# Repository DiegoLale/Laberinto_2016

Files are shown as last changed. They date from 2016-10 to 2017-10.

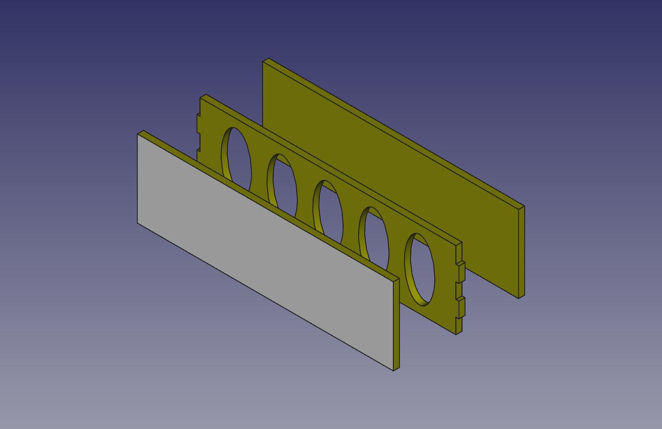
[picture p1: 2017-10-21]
piezas_laberinto/montaje paredes.jpeg

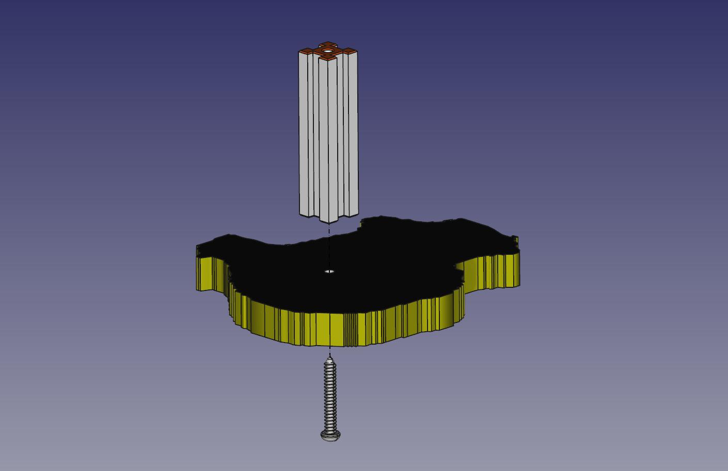
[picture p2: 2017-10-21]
piezas_laberinto/montaje_pivote.jpeg

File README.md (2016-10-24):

# Laberinto_2016
Simple robot para competición de laberinto de la OSHWDem

Toda la información en www.lalebots.com

***14 octubre 2016***

  Creación del repositorio
  
  Añadido primer chasis
  
***16 octubre 2016***

  Modificado chasis
  
    chasisSuperior_v2
    cahsisInferior_v2
    
  Añadidas nuevas piezas
  
    bolaLoca
    TapaBateria
    LlantaLego
    
*** 24 octubre 2016***

  Compartida electrónica

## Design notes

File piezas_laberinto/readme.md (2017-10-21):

Piezas para fabricación de laberinto con paredes de 12mm y distancia de 180mm entre "postes".
Hay una versión imprimible de las paredes y otra que se puede cortar en una cortadora láser.
El espesor de las paredes ha de ser de 12mm por lo que se usa madera de 4mm.
Cada pared está compuesta de tres piezas. una central con huecos que tiene pestañas laterales para encastrar en los "pilares",
Y otras dos planas para las partes exteriores.
El archivo "7paredes.dxf" está optimizado para hacer 7 paredes completas en una cortadora de al menos 52cm x 37mm.
Todos los diseños han sido creados con herramientas libres.
Freecad para los diseños 3d y librecad para los dxf.
Los pivotes están pensados para ser atornillados por debajo a un tablero de 10mm con tornillos din7981 de 25mm o m3 de al menos 20mm

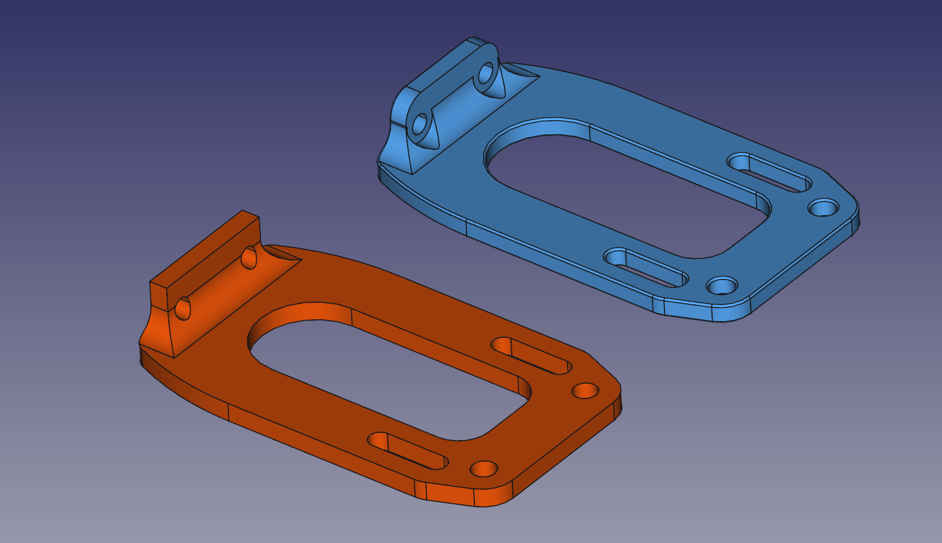
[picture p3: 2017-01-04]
soportes.png

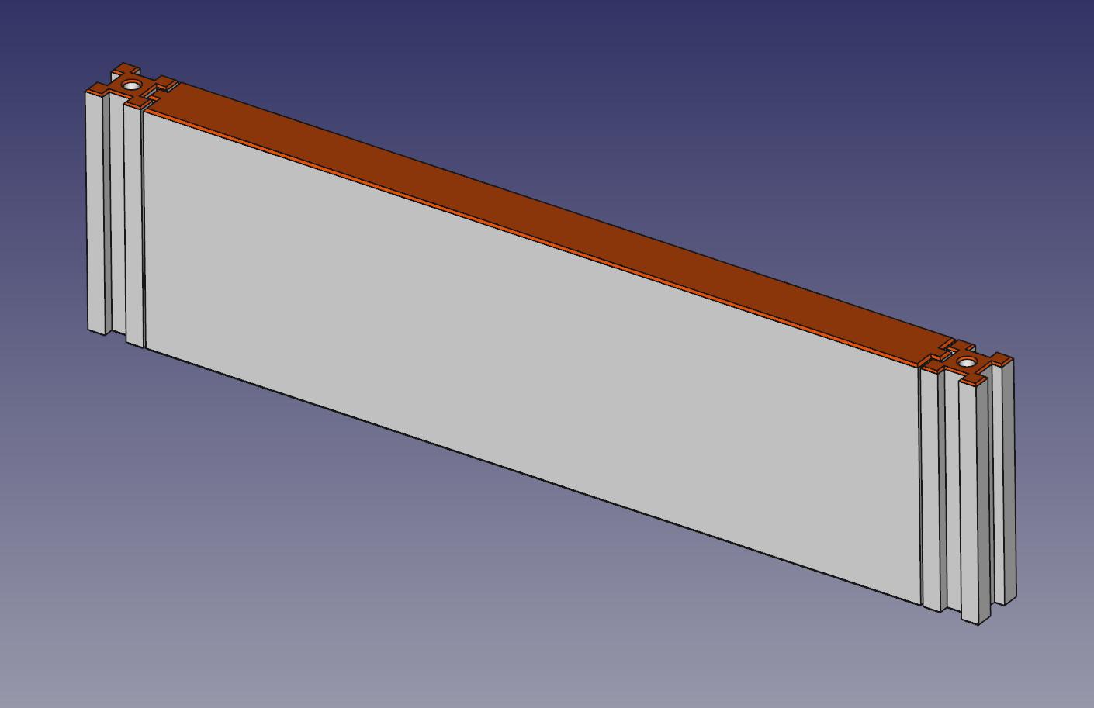
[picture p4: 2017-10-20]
piezas_laberinto/piezas_laberinto.jpeg

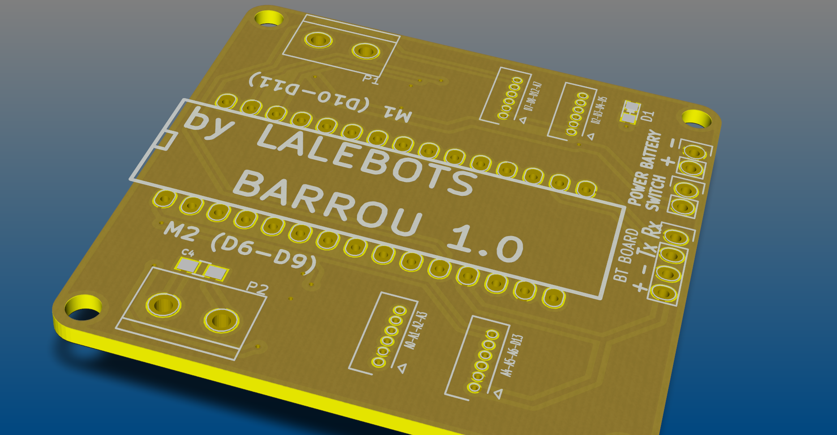
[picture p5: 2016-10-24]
PCB/aneja_2016.png

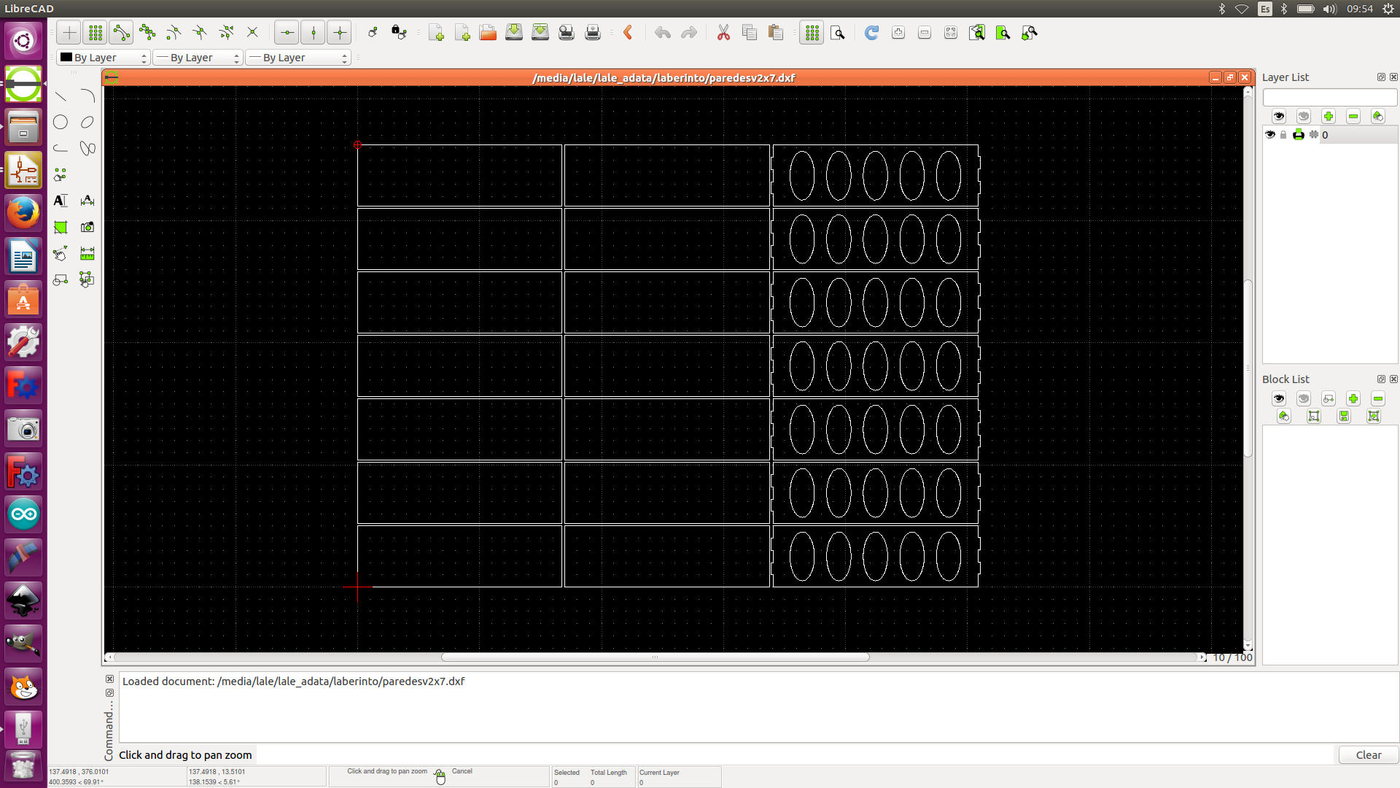
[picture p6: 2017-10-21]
piezas_laberinto/librecad paredes.png

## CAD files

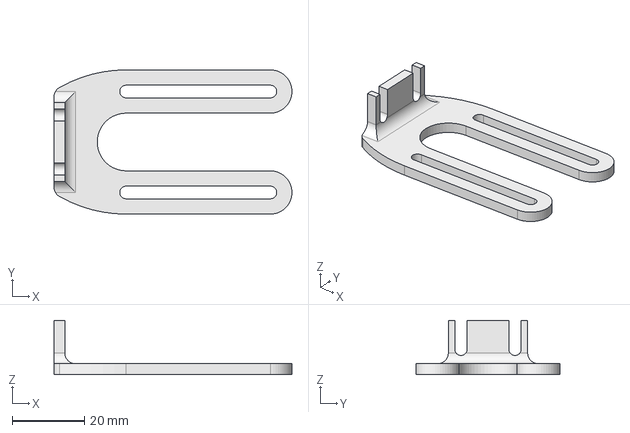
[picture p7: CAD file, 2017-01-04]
freecad/siguelineasSoporte.fcstd
66.0 x 40.0 x 15.0 mm

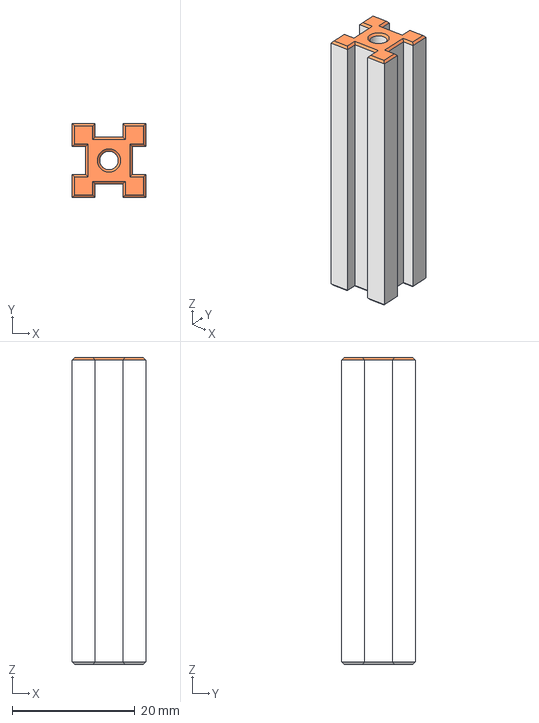
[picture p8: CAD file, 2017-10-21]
piezas_laberinto/pivote.step
12.0 x 12.0 x 50.0 mm

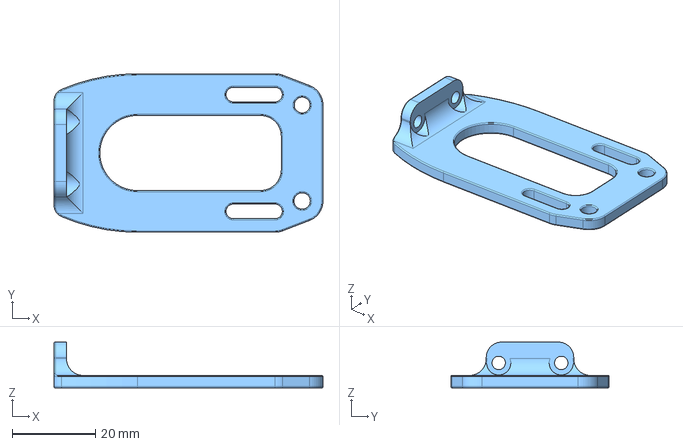
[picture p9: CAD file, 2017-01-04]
step/siguelineasSoportev2.step
64.5 x 38.0 x 11.0 mm

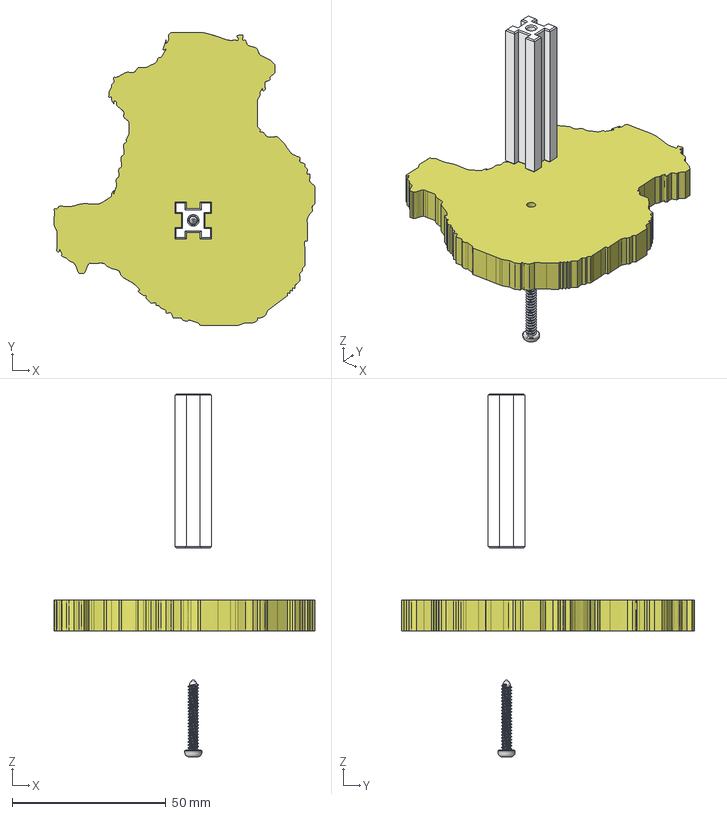
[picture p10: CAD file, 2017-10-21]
piezas_laberinto/montaje pivote.fcstd
84.8 x 95.3 x 118.0 mm
pivote

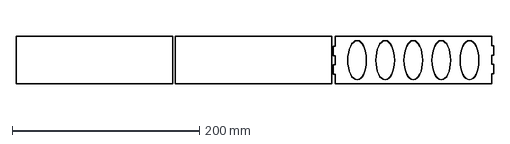
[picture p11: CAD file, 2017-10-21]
piezas_laberinto/#pared para laser.dxf
510.6 x 50.5 mm

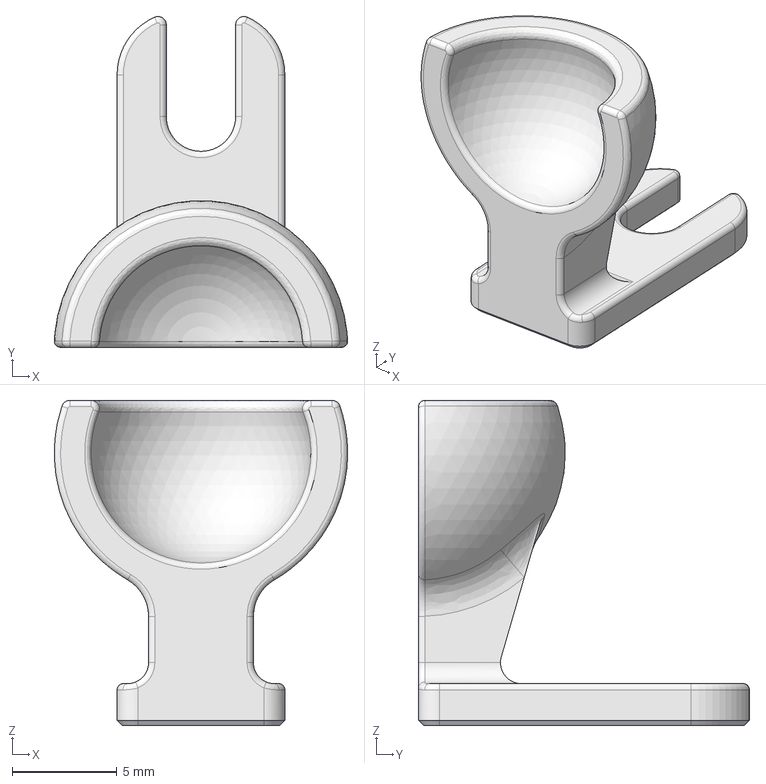
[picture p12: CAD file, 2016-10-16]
step/bolaLoca.step
14.0 x 15.8 x 15.5 mm

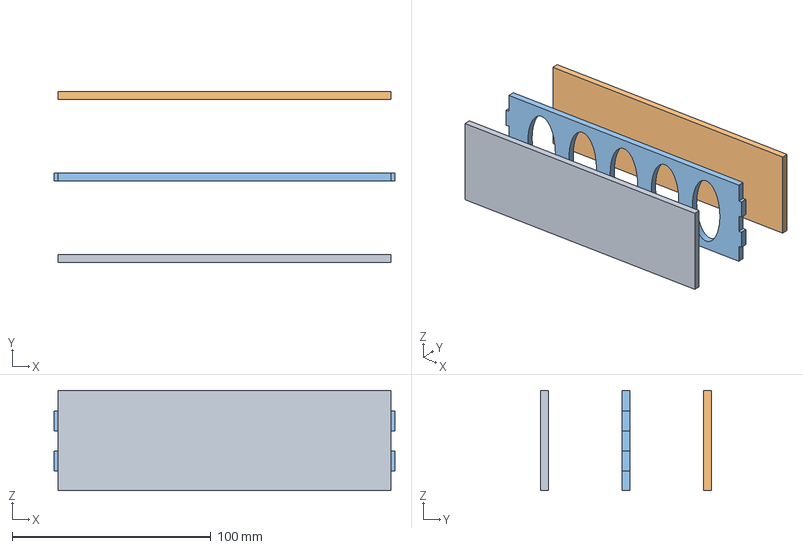
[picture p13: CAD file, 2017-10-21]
piezas_laberinto/montaje paredes.fcstd
171.6 x 86.0 x 50.5 mm
Cubo
Cubo001

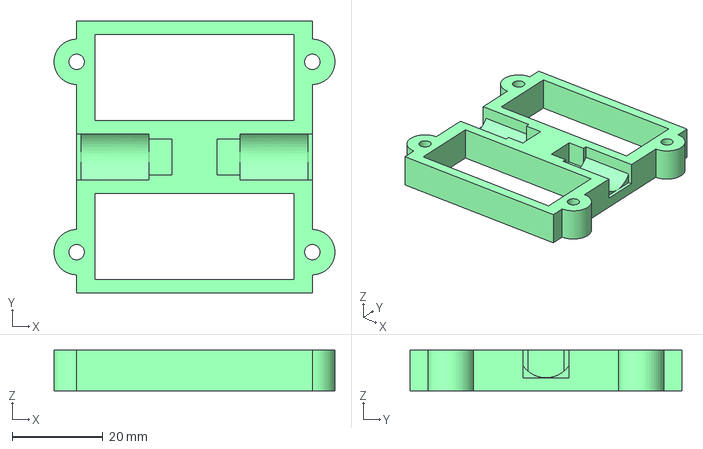
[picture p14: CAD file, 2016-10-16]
step/chasisInferior_v2.step
62.0 x 60.0 x 9.00 mm

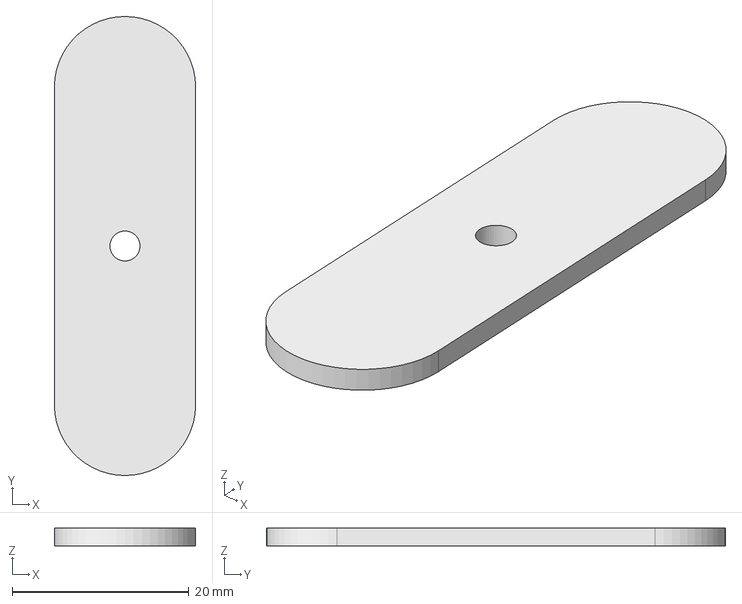
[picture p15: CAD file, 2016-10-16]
step/tapaBateriasSimple.step
16.0 x 52.0 x 2.00 mm

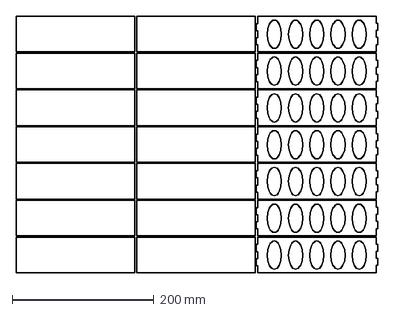
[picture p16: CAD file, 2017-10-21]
piezas_laberinto/7paredes.dxf
510.6 x 362.5 mm

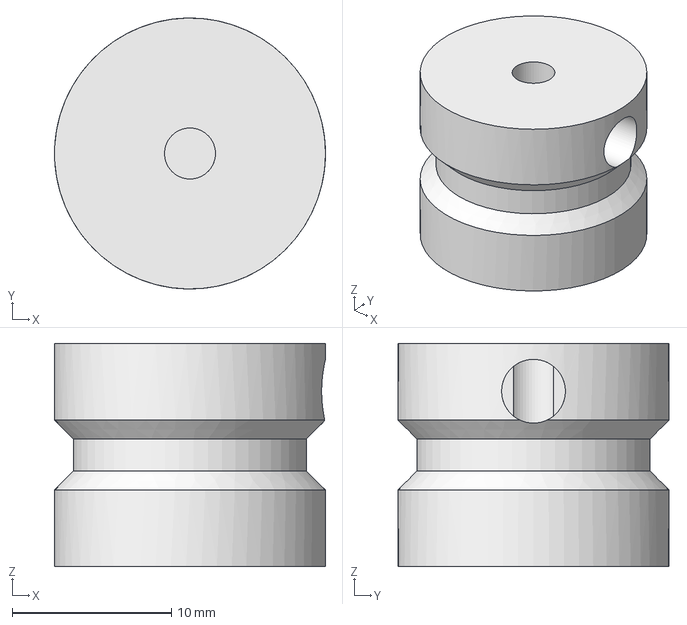
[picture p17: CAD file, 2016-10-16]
step/llantaLego.step
17.0 x 17.0 x 14.0 mm

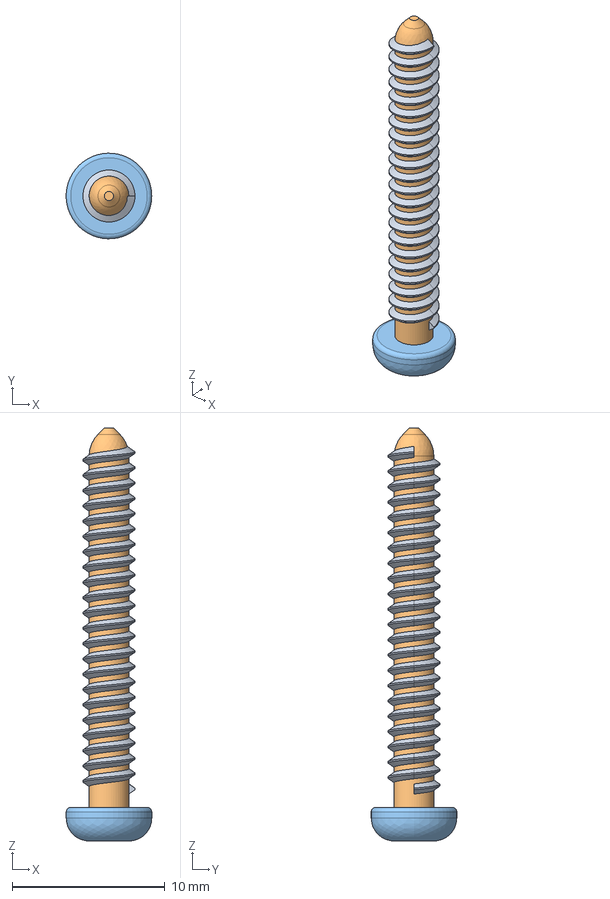
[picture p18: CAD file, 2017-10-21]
piezas_laberinto/tornillo7981_25mm.step
5.59 x 5.60 x 27.0 mm

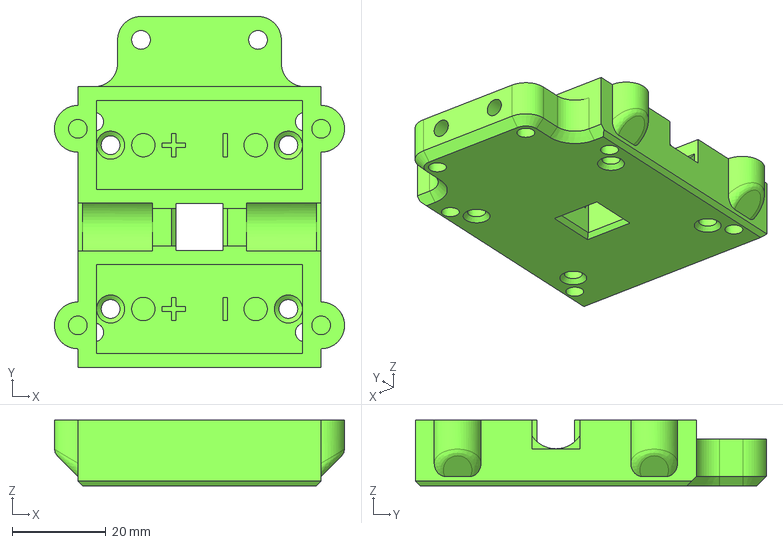
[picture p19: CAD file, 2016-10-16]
step/chasisSuperior_v2.step
62.0 x 75.0 x 14.0 mm

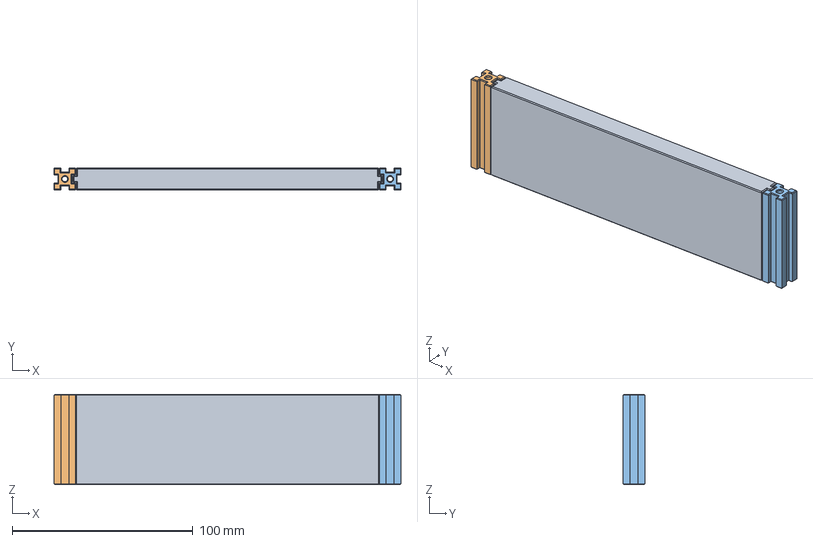
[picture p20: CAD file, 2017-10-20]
piezas_laberinto/piezas laberinto.fcstd
192.0 x 12.0 x 50.0 mm
pared
pivote
Clone of pivote

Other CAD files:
step/soporteSiguelineas.step
piezas_laberinto/pared.stl
piezas_laberinto/din7981.fcstd
step/chasisInferior.step
freecad/bolaLoca.fcstd
freecad/chasisInferior.fcstd
freecad/chasisInferior_v2.fcstd
freecad/chasisSuperior.fcstd
freecad/chasisSuperior_v2.fcstd
freecad/llantaLego.fcstd
freecad/siguelineasSoportev2.fcstd
freecad/tapaBateriasSimple.fcstd
piezas_laberinto/pared para laser.dxf
piezas_laberinto/pivote.stl
step/chasisSuperior.step
stl/bolaLoca.stl
stl/chasisInferior.stl
stl/chasisInferior_v2.stl
stl/chasisSuperior.stl
stl/chasisSuperior_v2.stl
stl/llantaLego.stl
stl/siguelineasSoporteV2.stl
stl/soporteSiguelineas.stl
stl/tapaBateriasSimple.stl

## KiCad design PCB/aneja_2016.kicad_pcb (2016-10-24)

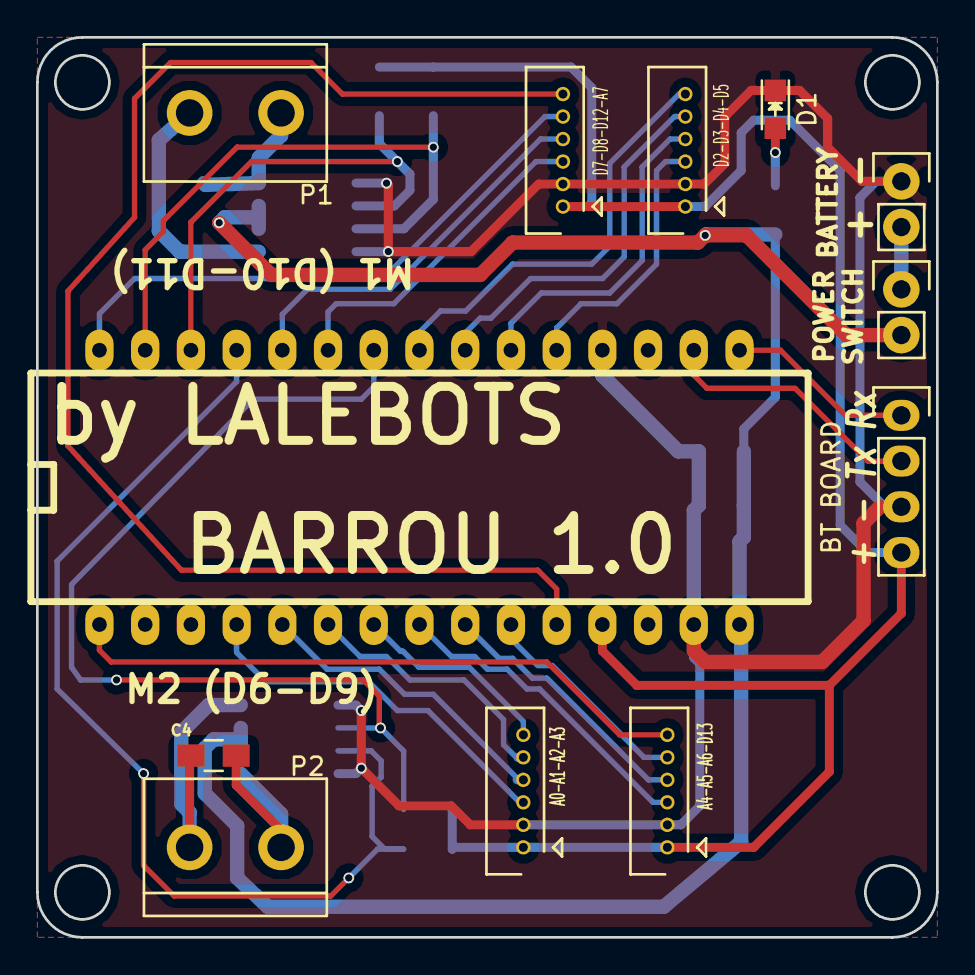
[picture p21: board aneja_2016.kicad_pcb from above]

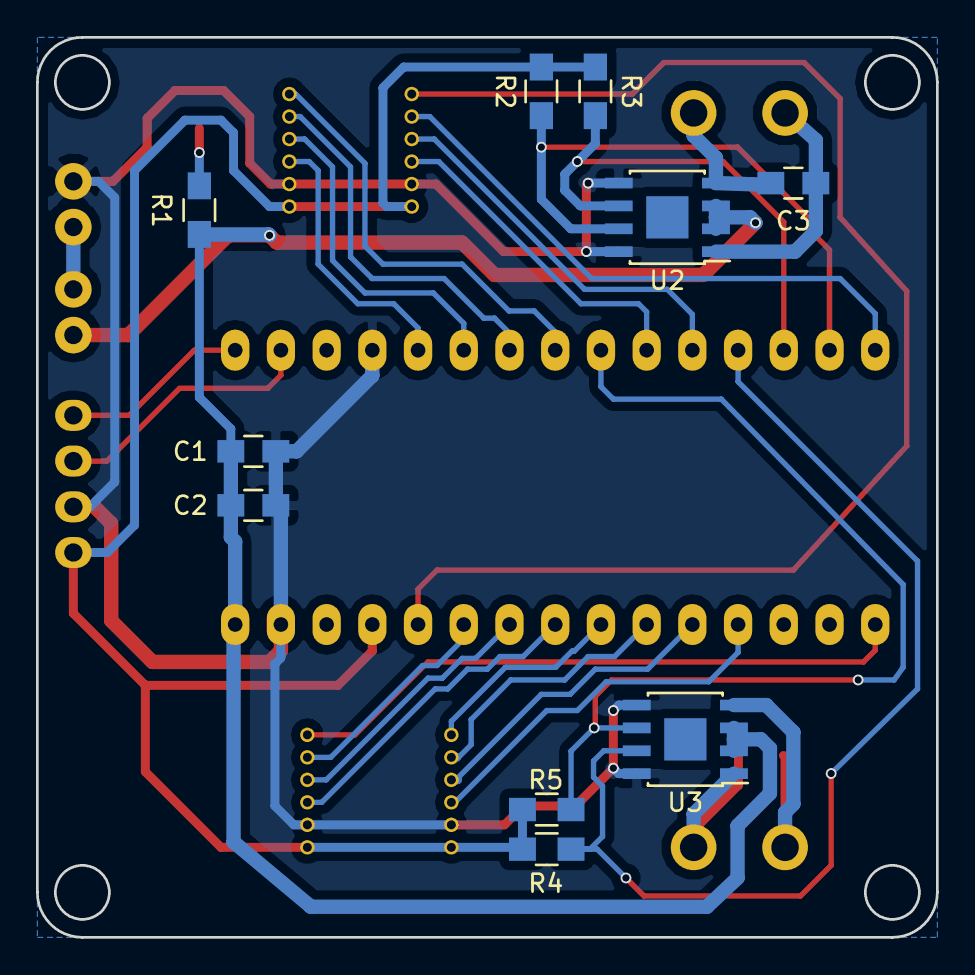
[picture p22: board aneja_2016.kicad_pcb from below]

Board: 2 copper layers, 50.0 x 50.0 mm, 22 parts (10 on the bottom side), 31 nets.

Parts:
A0-A1-A2-A3, A4-A5-A6-D13: CONN_01X06; Connector_Molex_PicoBlade_53047-0610
BT BOARD: BT_BOARD; Socket_Strip_Straight_1x04
C1, C2, C3, C4: C; C_0805_HandSoldering
D1: LED; LED-0805
D2-D3-D4-D5, D7-D8-D12-A7: CONN_01X06; Connector_Molex_PicoBlade_53047-0610
P1, P2: CONN_01X02; bornier2
P4, P5: CONN_01X02; Pin_Header_Straight_1x02
R1, R2, R3, R4, R5: R; R_0805_HandSoldering
U2, U3: hg7881; SOIC-8-1EP_3.9x4.9mm_Pitch1.27mm
by LALEBOTS: BARROU 1.0; arduino_mini

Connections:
/5v: A0-A1-A2-A3.1, A4-A5-A6-D13.1, BT BOARD.4, D2-D3-D4-D5.1, D7-D8-D12-A7.1, R2.1, R3.1, R4.1, R5.1, by LALEBOTS.12
/A0: A0-A1-A2-A3.3, by LALEBOTS.4
/A1: A0-A1-A2-A3.4, by LALEBOTS.5
/A2: A0-A1-A2-A3.5, by LALEBOTS.6
/A3: A0-A1-A2-A3.6, by LALEBOTS.7
/A4: A4-A5-A6-D13.3, by LALEBOTS.8
/A5: A4-A5-A6-D13.4, by LALEBOTS.9
/A6: A4-A5-A6-D13.5, by LALEBOTS.10
/A7: D7-D8-D12-A7.6, by LALEBOTS.11
/D2: D2-D3-D4-D5.3, by LALEBOTS.20
/D3: D2-D3-D4-D5.4, by LALEBOTS.21
/D4: D2-D3-D4-D5.5, by LALEBOTS.22
/D5: D2-D3-D4-D5.6, by LALEBOTS.23
/D7: D7-D8-D12-A7.3, by LALEBOTS.25
/D8: D7-D8-D12-A7.4, by LALEBOTS.26
/D12: D7-D8-D12-A7.5, by LALEBOTS.30
/D13: A4-A5-A6-D13.6, by LALEBOTS.1
/M1_a: R2.2, U2.7, by LALEBOTS.29
/M1_b: R3.2, U2.6, by LALEBOTS.28
/M2_a: R4.2, U3.7, by LALEBOTS.27
/M2_b: R5.2, U3.6, by LALEBOTS.24
/RX_arduino: BT BOARD.2, by LALEBOTS.17
/TX_arduino: BT BOARD.1, by LALEBOTS.16
/VIN: C1.1, C2.1, P5.2, R1.1, U2.2, U2.3, U3.2, U3.3, by LALEBOTS.15
GND: A0-A1-A2-A3.2, A4-A5-A6-D13.2, BT BOARD.3, C1.2, C2.2, D1.1, D2-D3-D4-D5.2, D7-D8-D12-A7.2, P4.1, U2.5, U2.8, U3.5, U3.8, by LALEBOTS.14, by LALEBOTS.19
unnamed: C3.1, P1.2, U2.1
unnamed: C3.2, P1.1, U2.4
unnamed: C4.1, P2.2, U3.1
unnamed: C4.2, P2.1, U3.4
unnamed: D1.2, R1.2
unnamed: P4.2, P5.1

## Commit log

2016-10-15 chasis inicial
    [chasisInferior.fcstd, chasisInferior.step, chasisInferior.stl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]
2016-10-16 agregadas nuevas piezas
    [bolaLoca.fcstd, bolaLoca.step, bolaLoca.stl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]
2016-10-24 pcb compartida
    [aneja_2016.kicad_pcb, aneja_2016.sch]
2017-10-20 piezas para laberinto
    [piezas laberinto.fcstd]
2017-10-20 piezas laberinto
    [pared.stl, piezas laberinto.fcstd, pivote.stl]
2017-10-21 añadidas todas las piezas inprimibles o para corte laser del laberinto
    [#pared para laser.dxf, 7paredes.dxf, din7981.fcstd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]
